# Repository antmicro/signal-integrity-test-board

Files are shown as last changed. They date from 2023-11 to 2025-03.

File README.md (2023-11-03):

# Antmicro's Signal Integrity Test Board

Copyright (c) 2023 [Antmicro](https://www.antmicro.com)

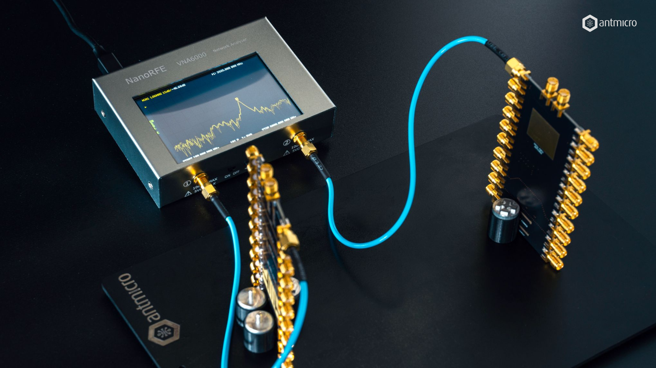
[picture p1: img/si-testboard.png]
Signal Integrity Testboard


## Overview

This project contains open hardware design files for a test board implementing various routing topologies.
The board can be used for calibrating and comparing measurements of signal propagation properties with Vector Network Analyzers (VNAs).
It can also be used for SI, EMI or EMC simulations with field solvers.
The board was designed in KiCad 6.x.

## Project structure

The main directory contains the KiCad design files, a LICENSE and a README.
The remaining files are stored in the following directories:

* ``img`` - contains graphics for this README
* ``doc`` - contains generated schematics and other documentation
* ``lib`` - contains KiCad component library
* ``assets`` - contains visual content used for showcasing the board on [Open Hardware Portal](https://openhardware.antmicro.com)

## Key features

* 4-layer PCB designed in defined impedance
* Includes SMA ports connected to copper primitives which implement the following features:

  * VNA calibration port terminated with 50Ohm
  * VNA calibration port open (i.e. not terminated)
  * VNA calibration port shorted (grounded) 
  * Single stripline
  * Differential pair stripline
  * Stripline with long stub
  * Stripline with short stub
  * Digital bandpass filter
  * Reference stripline layout with layer-change
  * Simple planar antenna
  * Not-terminated striplines with tight and loose meander of the same lengths

## License

This project is licensed under the [Apache-2.0](LICENSE) license.

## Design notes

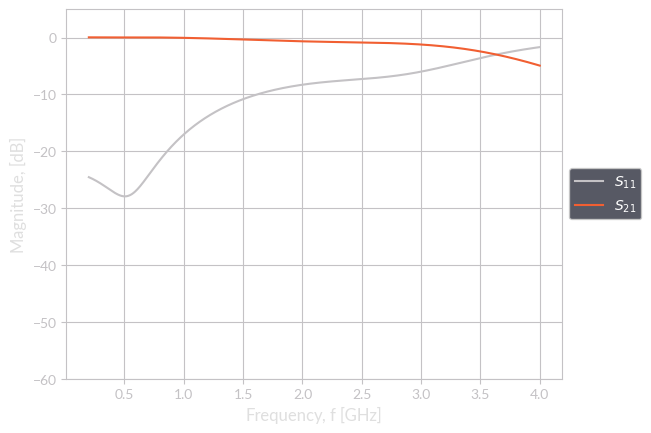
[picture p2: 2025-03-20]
assets/si/short-stub/S_x1.png

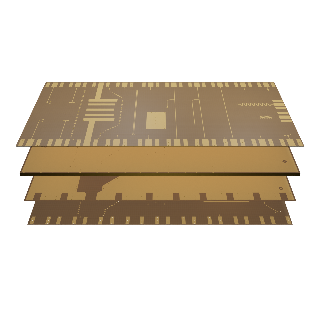
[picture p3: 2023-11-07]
assets/previews/layer1_thumbnail.webp

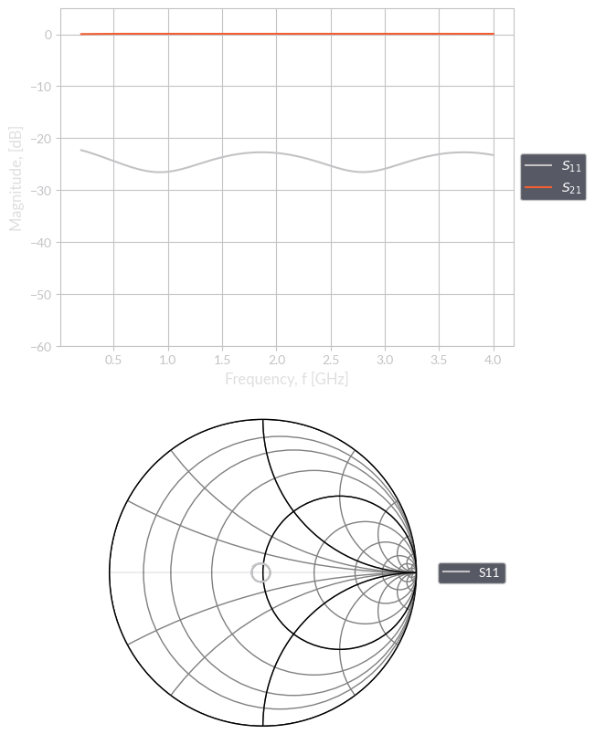
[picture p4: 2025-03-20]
assets/si/pass/s_param_and_smith_1.png

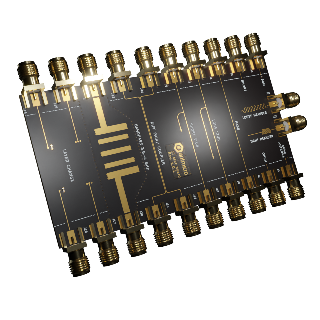
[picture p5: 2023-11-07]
assets/previews/leftT_thumbnail.png

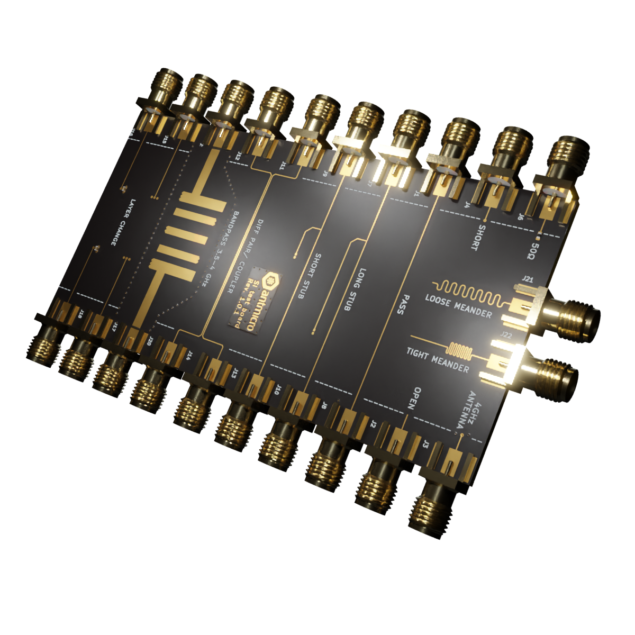
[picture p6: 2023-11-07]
assets/previews/rightT.webp

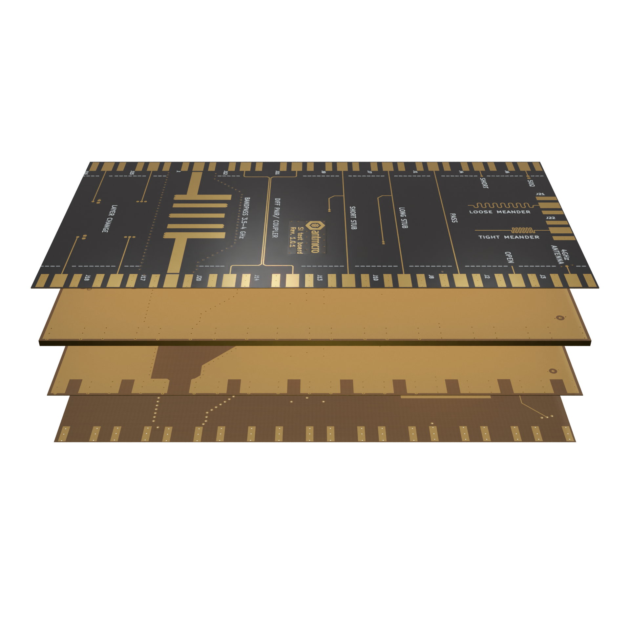
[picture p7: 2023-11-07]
assets/previews/stackup.png

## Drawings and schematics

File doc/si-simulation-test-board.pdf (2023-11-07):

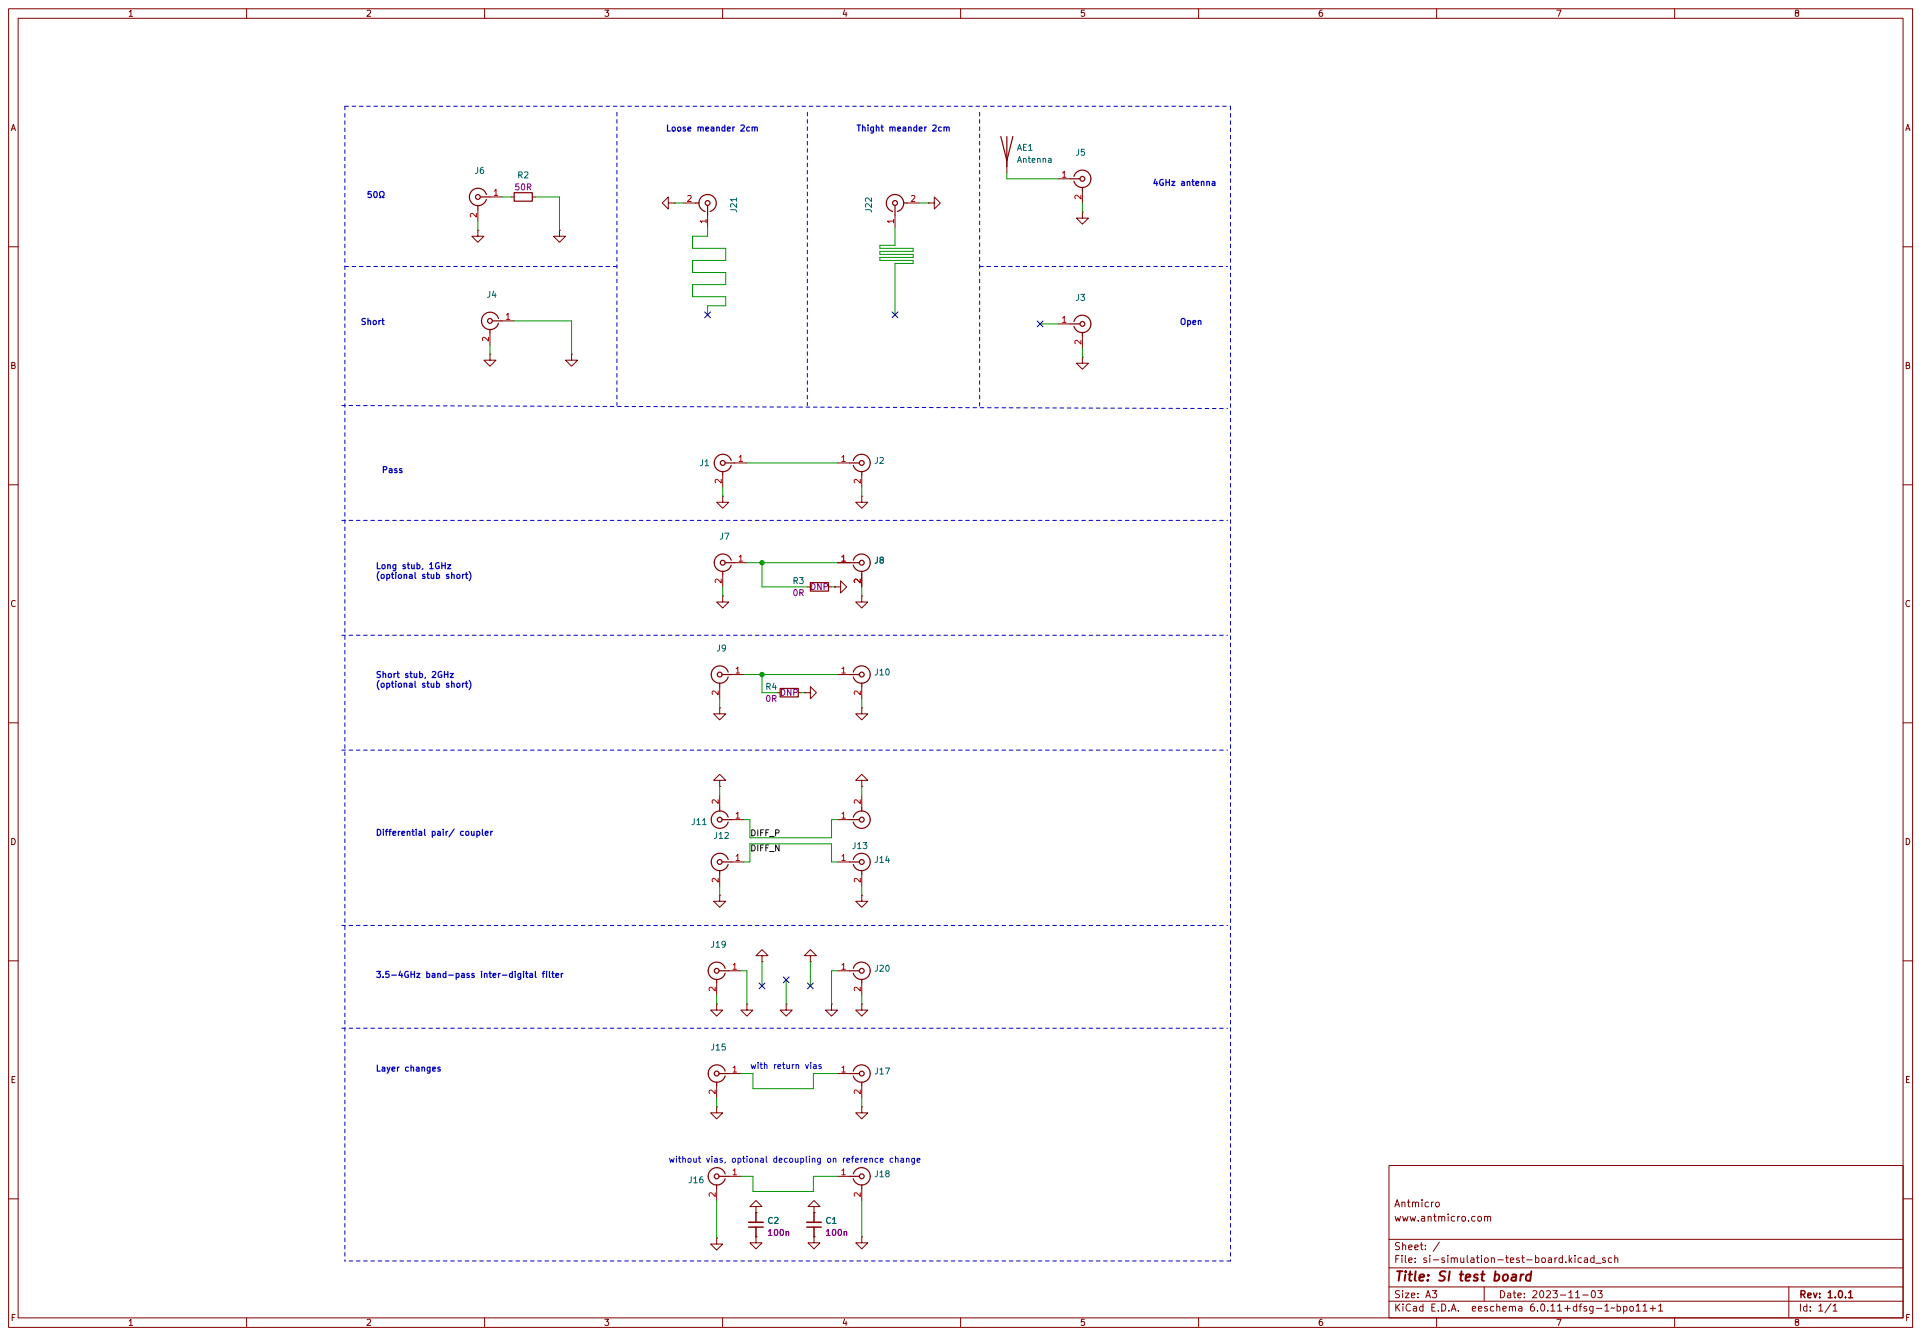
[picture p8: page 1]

Long stub, 1GHz
(optional stub short) Short stub, 2GHz

Antmicro
File: si-simulation-test-board.kicad_sch Sheet: / www.antmicro.com

Id: 1/1 Title: SI test board

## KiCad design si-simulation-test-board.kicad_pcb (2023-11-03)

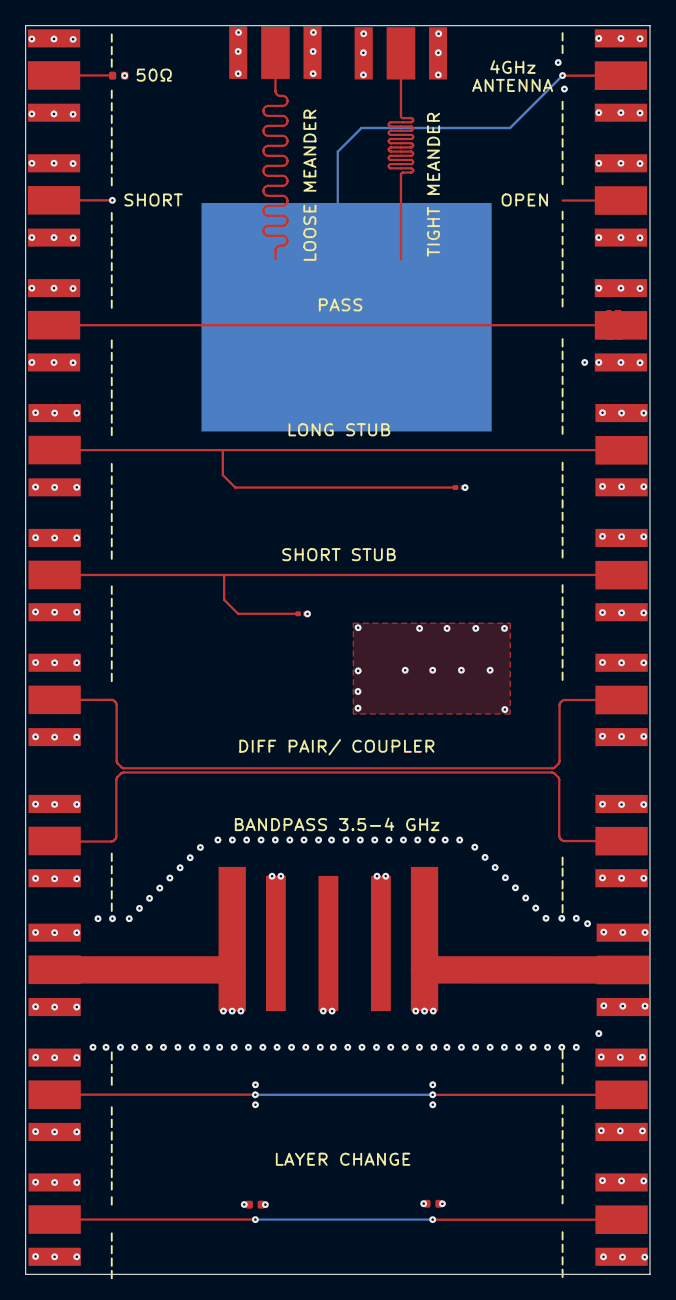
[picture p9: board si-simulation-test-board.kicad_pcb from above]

Board: 4 copper layers, 50.0 x 100.0 mm, 27 parts (0 on the bottom side), 9 nets.

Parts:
C1, C2: C_100n_0402; C_0402_1005Metric
J1, J2, J3, J4, J5, J6, J7, J8, J9, J10, J11, J12, J13, J14, J15, J16, J17, J18, J19, J20, J21, J22: Conn_SMA_RF2-143-T-17-50-G; RF_SMA_BoardEdge_RF2-143-T-17-50-G
R2: R_50R_0402; R_0402_1005Metric
R3, R4: R_0R_0201; R_0201

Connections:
/DIFF_N: J12.1, J14.1
/DIFF_P: J11.1, J13.1
GND: C1.1, C1.2, C2.1, C2.2, J1.2, J2.2, J3.2, J4.1, J4.2, J5.2, J6.2, J7.2, J8.2, J9.2, J10.2, J11.2, J12.2, J13.2, J14.2, J15.2, J16.2, J17.2, J18.2, J19.1, J19.2, J20.1, J20.2, J21.2, J22.2, R2.2, R3.1, R4.1
unnamed: J1.1, J2.1
unnamed: J7.1, J8.1, R3.2
unnamed: J9.1, J10.1, R4.2
unnamed: J15.1, J17.1
unnamed: J16.1, J18.1
unnamed: J6.1, R2.1

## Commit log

2023-08-31 Draft a schematic
    [si-simulation-test-board.kicad_sch]
2023-08-31 Route PCB WiP
    [si-simulation-test-board.kicad_pcb]
2023-08-31 Finish PCB
    [si-simulation-test-board.kicad_pcb]
2023-11-03 Improve schematic clarity
    [si-simulation-test-board.kicad_sch]
2023-11-03 Correct silkscreen 'tight meander' text
    [si-simulation-test-board.kicad_pcb]
2023-11-03 Clean DRC, add missing cutouts for upper connectors, fix antenna feed point, standarize footprint, bump to 1.0.1
    [si-simulation-test-board.kicad_sch]
2023-11-03 Make SCH A3 landscape
    [si-simulation-test-board.kicad_sch]
2023-11-03 Add local libraries
    [si-simulation-test-board.kicad_sch]
2023-11-07 Update gitignore, add stackup.csv
    [stackup.csv]
2025-03-20 [#74509] Add SI assets
    [Port_0_data.csv, Port_2_data.csv]
2025-03-21 [#74509] Update SI assets
    [Port_0_data.csv, Port_2_data.csv]

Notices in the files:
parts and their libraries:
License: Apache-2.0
